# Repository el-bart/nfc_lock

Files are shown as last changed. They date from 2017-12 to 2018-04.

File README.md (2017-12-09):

# NFC lock

NFC-based, battery-powered lock for drawers, closets, etc.
android app used to control the module.

## done

* android app communicating with NFC both ways.

## TODO

* PCB with M24SR + STM8S003xx.
* SW for I2C communication with NFC tag.
* SW for controlling 2 servo mechanisms.
* 3D-printed box for servo and battery mounting.

## ideas / improvements

* configurable servos' min/max positions.
* android app look-and-feel update... ;)
* use ATECC508A crypto chip for limiting access to drawer/lock.

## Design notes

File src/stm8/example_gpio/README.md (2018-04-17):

# LED blinking example

example LED-blinking project, based on STM's example code.

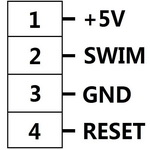
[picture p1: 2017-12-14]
doc/swim.jpg

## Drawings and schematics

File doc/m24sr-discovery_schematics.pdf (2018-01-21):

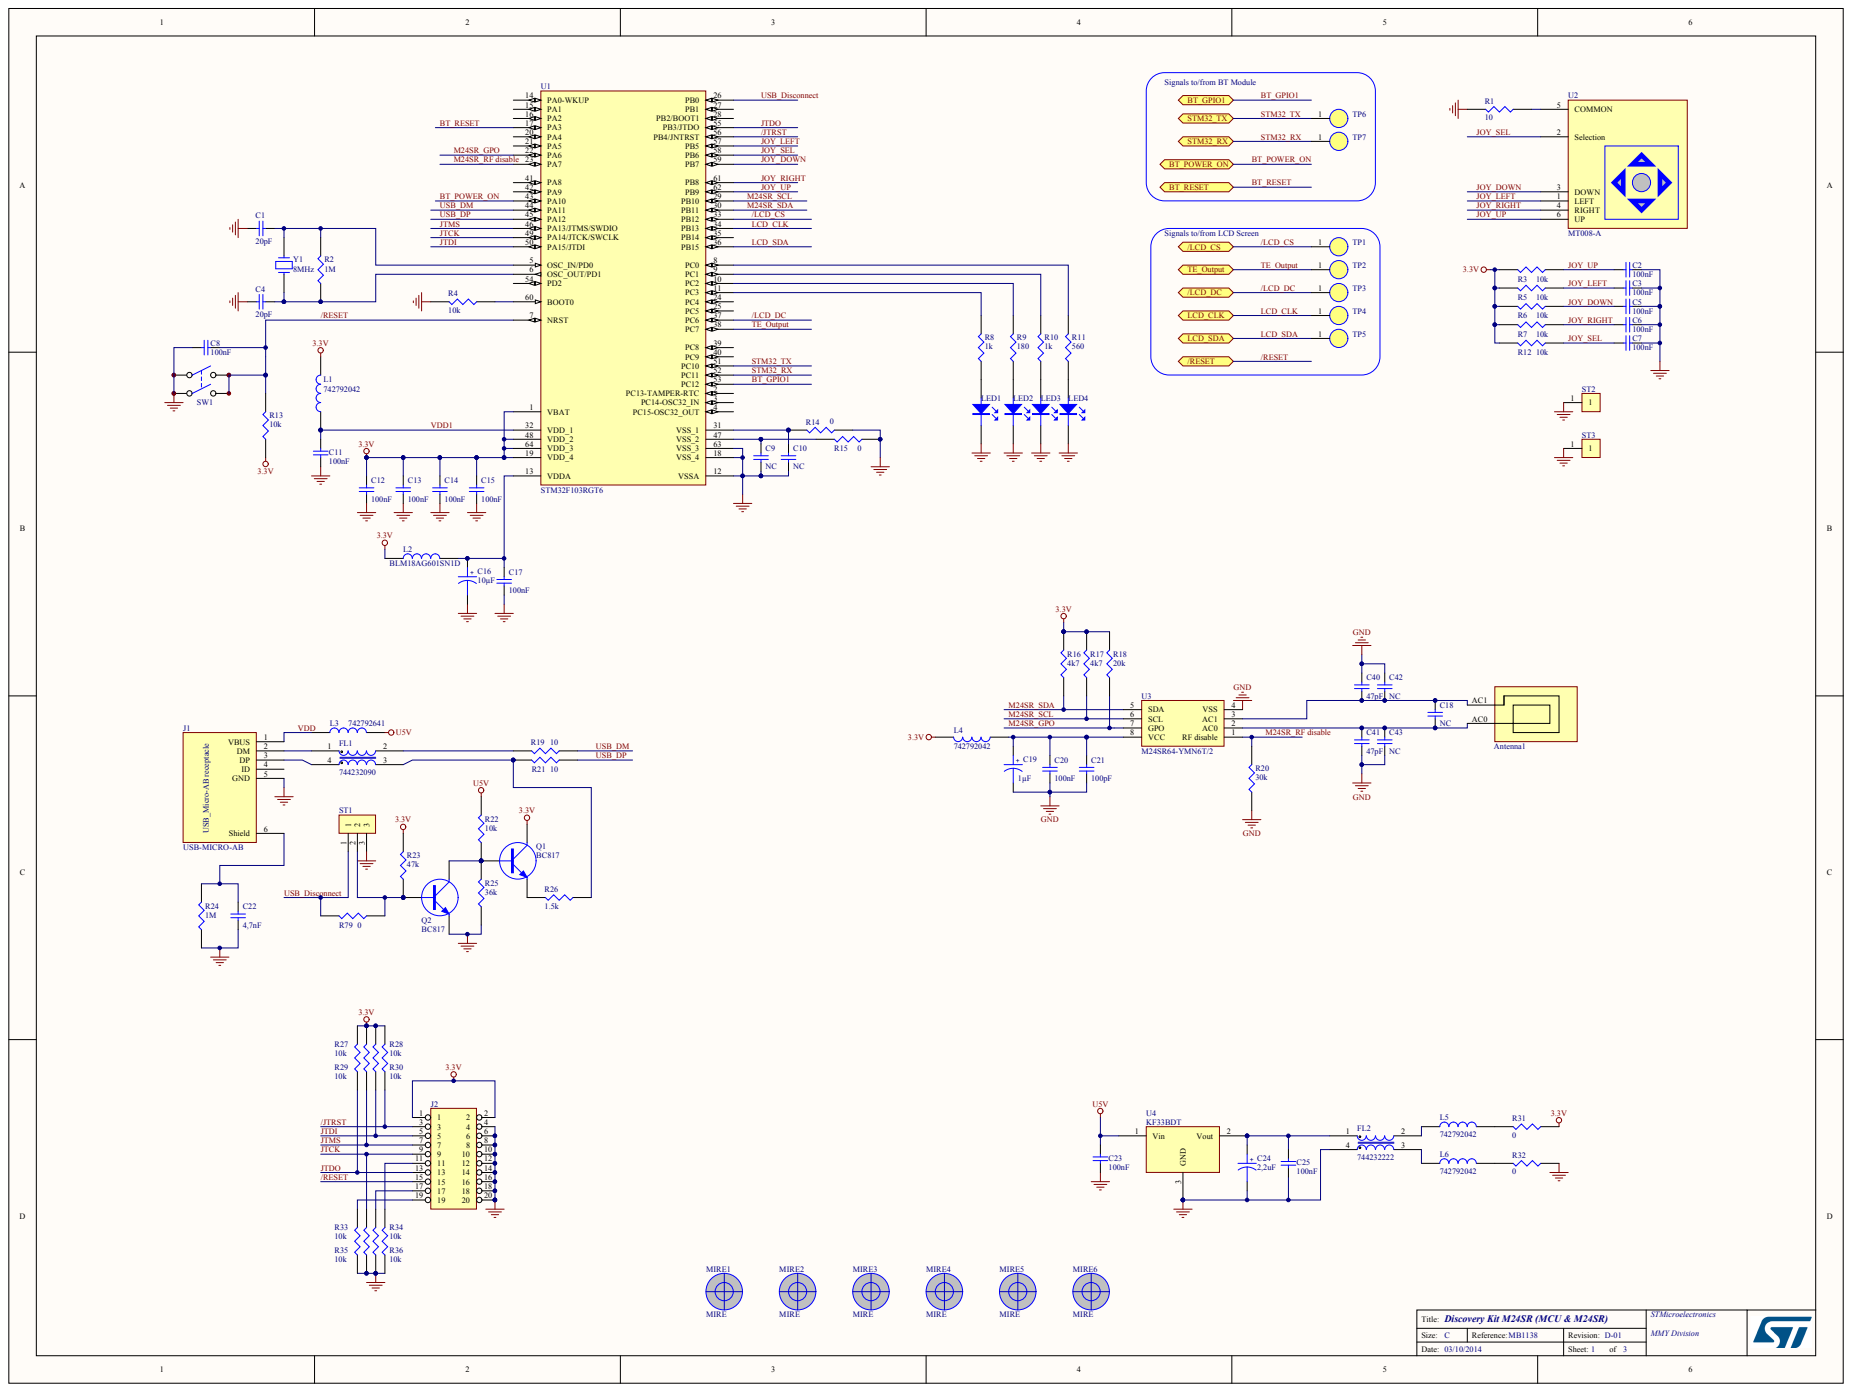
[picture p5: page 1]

Signals to/from BT Module

Signals to/from LCD Screen

Title: Discovery Kit M24SR (MCU & M24SR) | STMicroelectronics MMY Division

Size: C | Reference: MB1138 | Revision: D-01

Date: | | Sheet: of

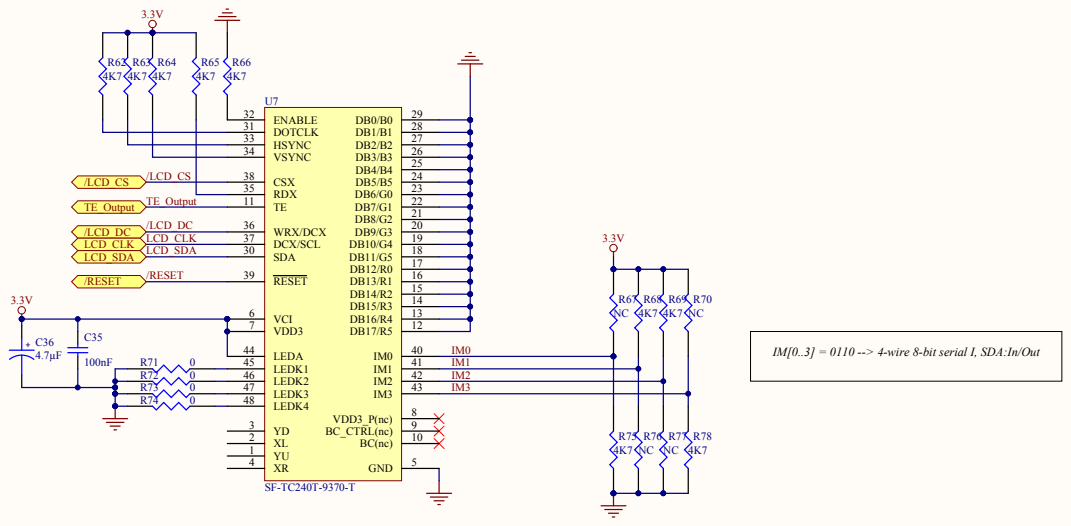
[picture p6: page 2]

IM[0..3] = 0110 --> 4-wire 8-bit serial I, SDA:In/Out

Discovery Kit M24SR (LCD Screen) | ST Microelectronics

A3 | | Revision:

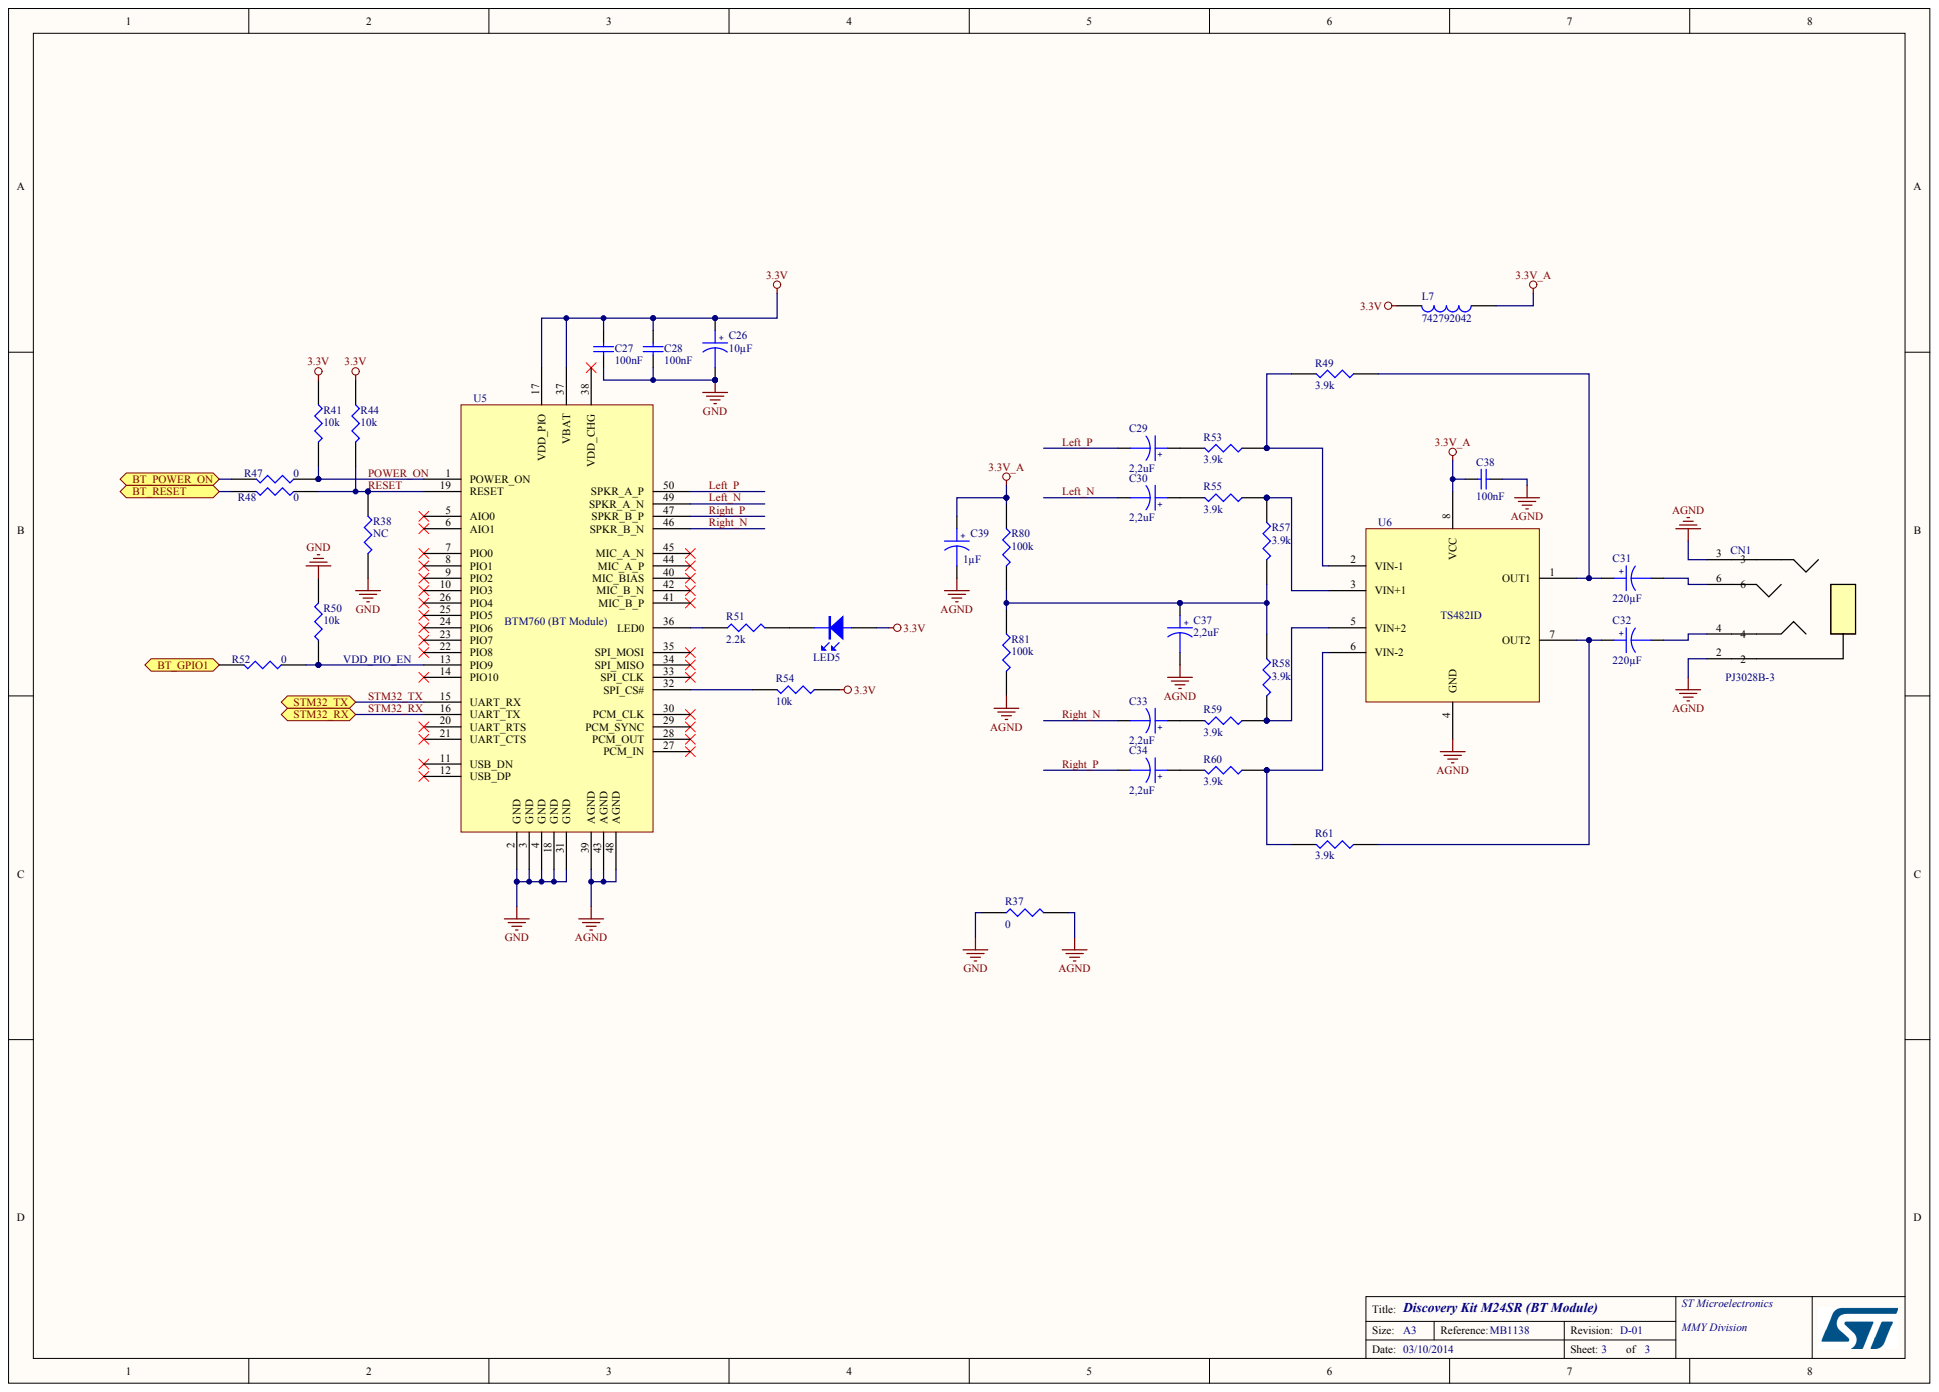
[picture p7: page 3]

Discovery Kit M24SR (BT Module) | ST Microelectronics

A3 | | Revision:

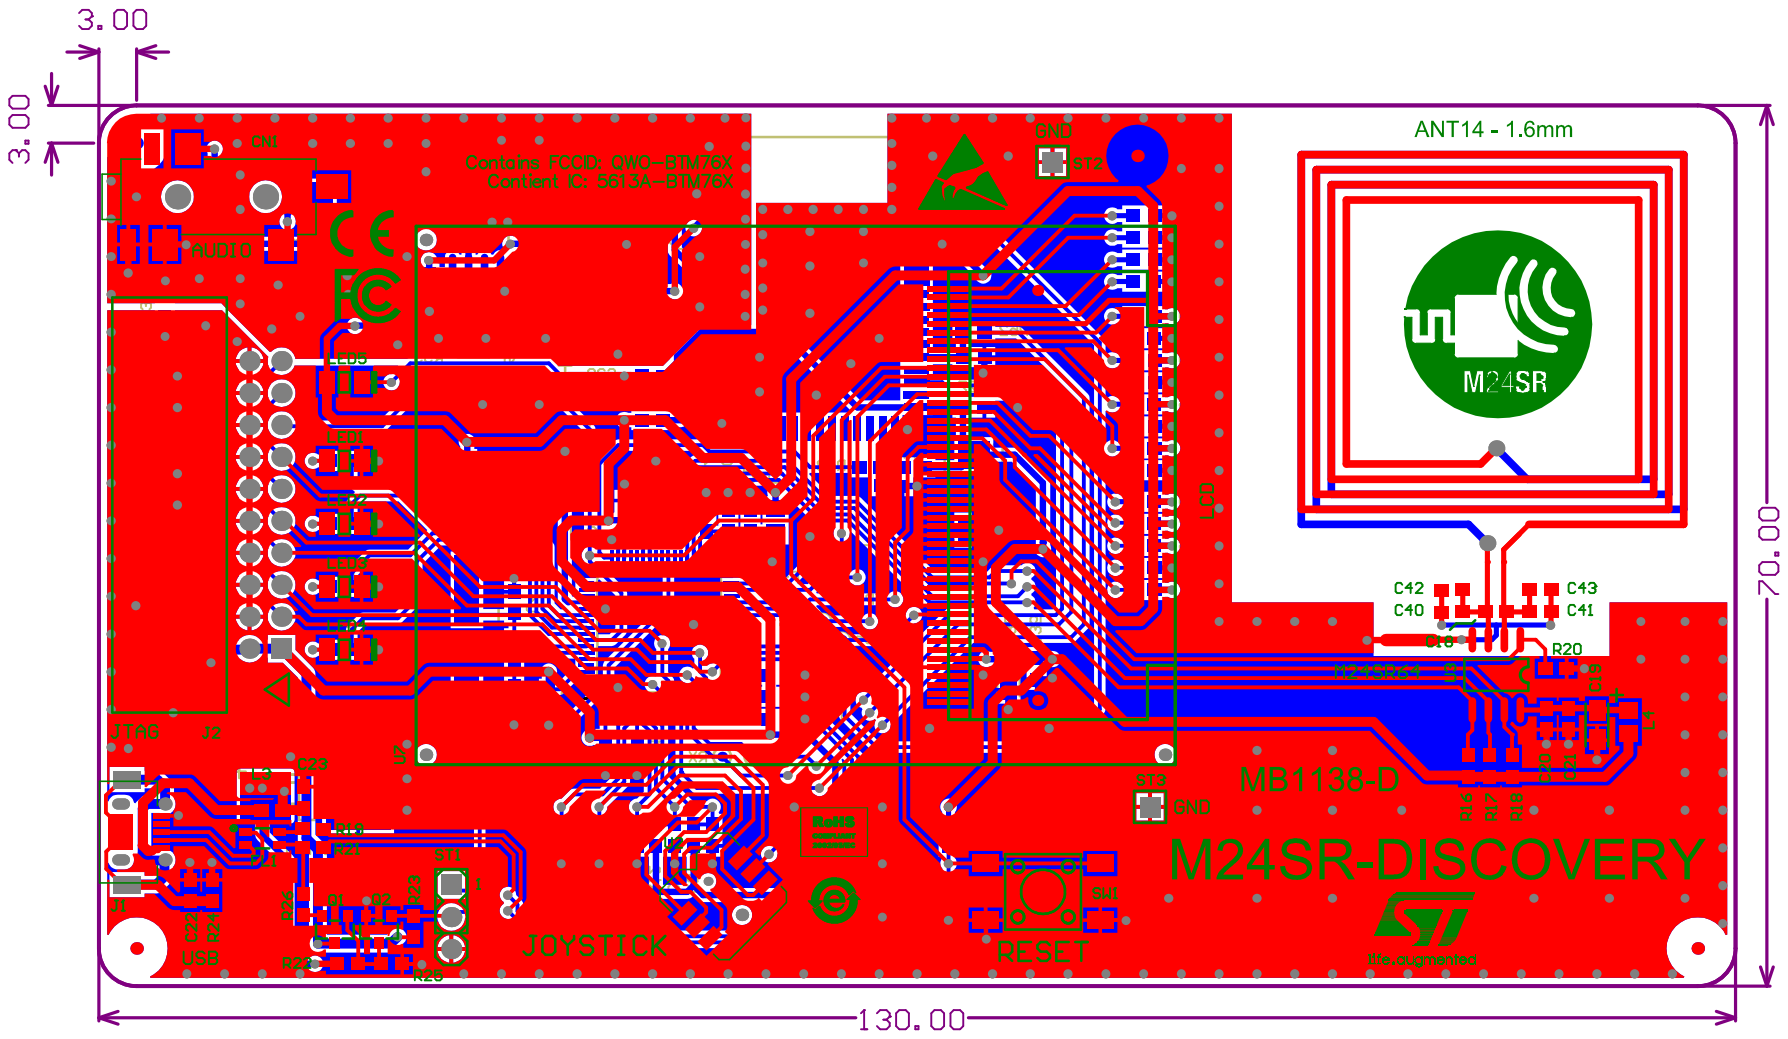
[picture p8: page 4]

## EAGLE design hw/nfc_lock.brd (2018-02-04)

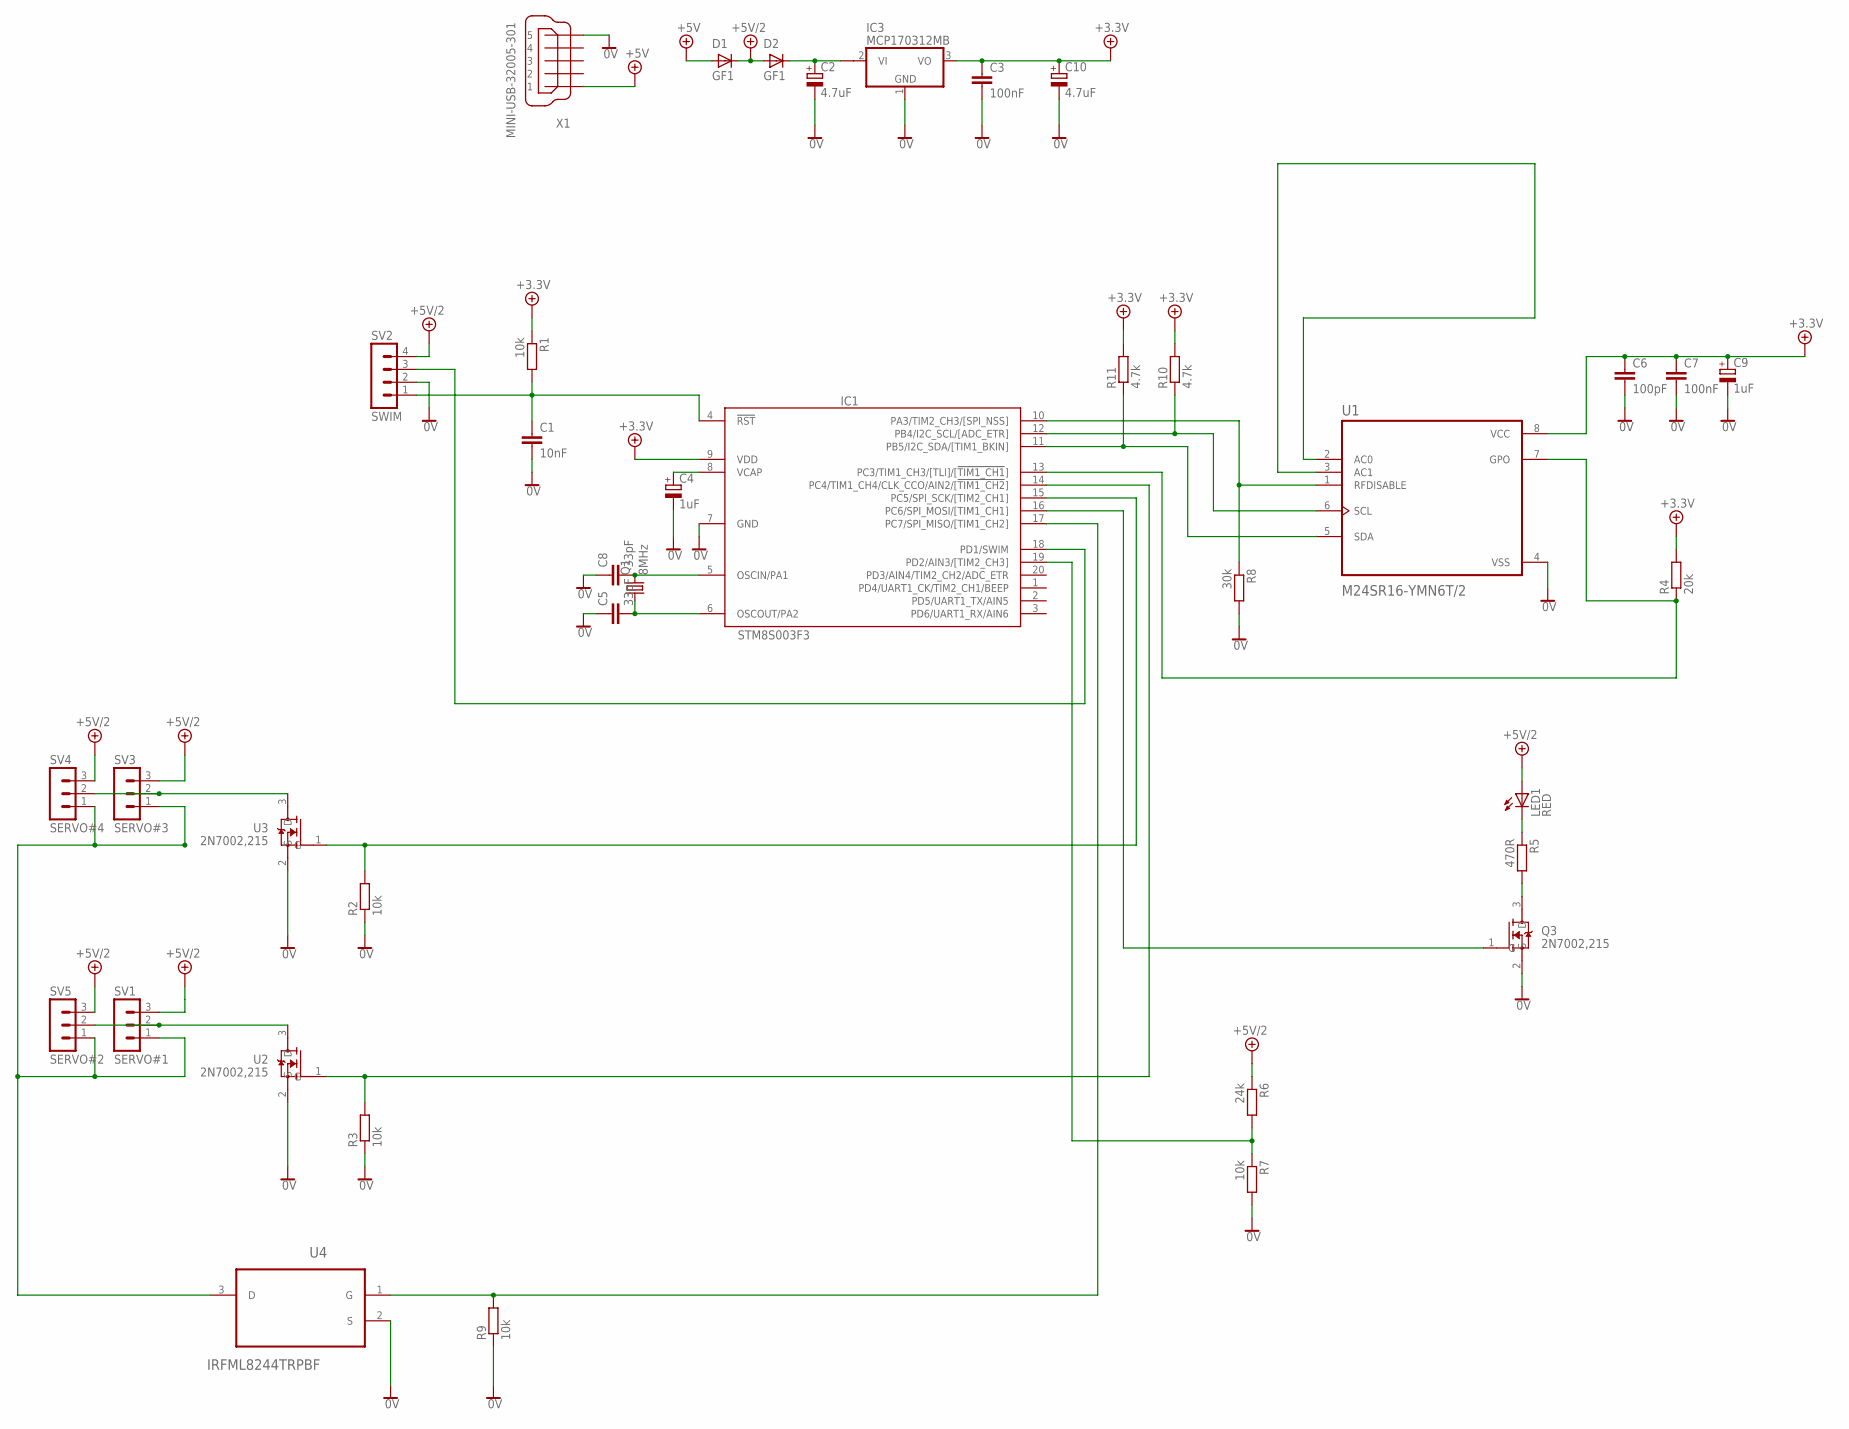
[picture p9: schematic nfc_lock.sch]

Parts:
C1: 10nF; C0603K
C2, C10: 4.7uF; 153CLV-0405
C3, C7: 100nF; C1206
C4, C9: 1uF; 153CLV-0405
C5, C8: 33pF; C0603K
C6: 100pF; C1206
D1, D2: GF1; SMA-DO214AC
IC1: STM8S003F3; TSSOP20
IC3: MCP170312MB; SOT89
LED1: RED; CHIP-LED0603
Q1: 8MHz; SM49
Q3: 2N7002,215; SOT95P230X110-3N
R1, R2, R3, R7, R9: 10k; R0805
R4: 20k; R0805
R5: 470R; R0805
R6: 24k; R0805
R8: 30k; R0805
R10, R11: 4.7k; R0805
SV1: SERVO#1; MA03-1
SV2: SWIM; MA04-1
SV3: SERVO#3; MA03-1
SV4: SERVO#4; MA03-1
SV5: SERVO#2; MA03-1
U1: M24SR16-YMN6T/2; SOIC127P600X175-8N
U2, U3: 2N7002,215; SOT95P230X110-3N
U4: IRFML8244TRPBF; SOT95P240X112-3N
X1: MINI-USB-32005-301; 32005-301

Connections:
0V: C1.2, C2.-, C3.2, C4.-, C5.1, C6.2, C7.2, C8.1, C9.-, C10.-, IC1.7 (GND), IC3.1 (GND), Q3.2 (S), R2.1, R3.1, R7.2, R8.2, R9.1, SV2.2, U1.4 (VSS), U2.2 (S), U3.2 (S), U4.2 (S), X1.5
+5V: D1.A, X1.1
+5V/1: C3.1, C6.1, C7.1, C9.+, C10.+, IC1.9 (VDD), IC3.3 (VO), R1.1, R4.2, R10.2, R11.2, U1.8 (VCC)
+5V/2: D1.K (C), D2.A, LED1.A, R6.1, SV1.3, SV2.4, SV3.3, SV4.3, SV5.3
ANTENA: U1.2 (AC0), U1.3 (AC1)
CTRL_LED: IC1.16 (PC6/SPI_MOSI/[TIM1_CH1]), Q3.1 (G)
unnamed: C2.+, D2.K (C), IC3.2@1 (VI1)
unnamed: C1.1, IC1.4 (!RST), R1.2, SV2.1
unnamed: IC1.18 (PD1/SWIM), SV2.3
unnamed: IC1.10 (PA3/TIM2_CH3/[SPI_NSS]), R8.1, U1.1 (RFDISABLE)
unnamed: IC1.13 (PC3/TIM1_CH3/[TLI]/[!TIM1_CH1!]), R4.1, U1.7 (GPO)
unnamed: SV1.2, SV5.2, U2.3 (D)
unnamed: SV3.2, SV4.2, U3.3 (D)
unnamed: LED1.C, R5.1
unnamed: Q3.3 (D), R5.2
unnamed: C4.+, IC1.8 (VCAP)
unnamed: C8.2, IC1.5 (OSCIN/PA1), Q1.2
unnamed: C5.2, IC1.6 (OSCOUT/PA2), Q1.1
unnamed: IC1.19 (PD2/AIN3/[TIM2_CH3]), R6.2, R7.1
SCL: IC1.12 (PB4/I2C_SCL/[ADC_ETR]), R10.1, U1.6 (SCL)
SDA: IC1.11 (PB5/I2C_SDA/[TIM1_BKIN]), R11.1, U1.5 (SDA)
SERVO_GND: SV1.1, SV3.1, SV4.1, SV5.1, U4.3 (D)
SERVO_PACK_1: IC1.14 (PC4/TIM1_CH4/CLK_CCO/AIN2/[!TIM1_CH2!]), R3.2, U2.1 (G)
SERVO_PACK_2: IC1.15 (PC5/SPI_SCK/[TIM2_CH1]), R2.2, U3.1 (G)
SERWO_PWR: IC1.17 (PC7/SPI_MISO/[TIM1_CH2]), R9.2, U4.1 (G)

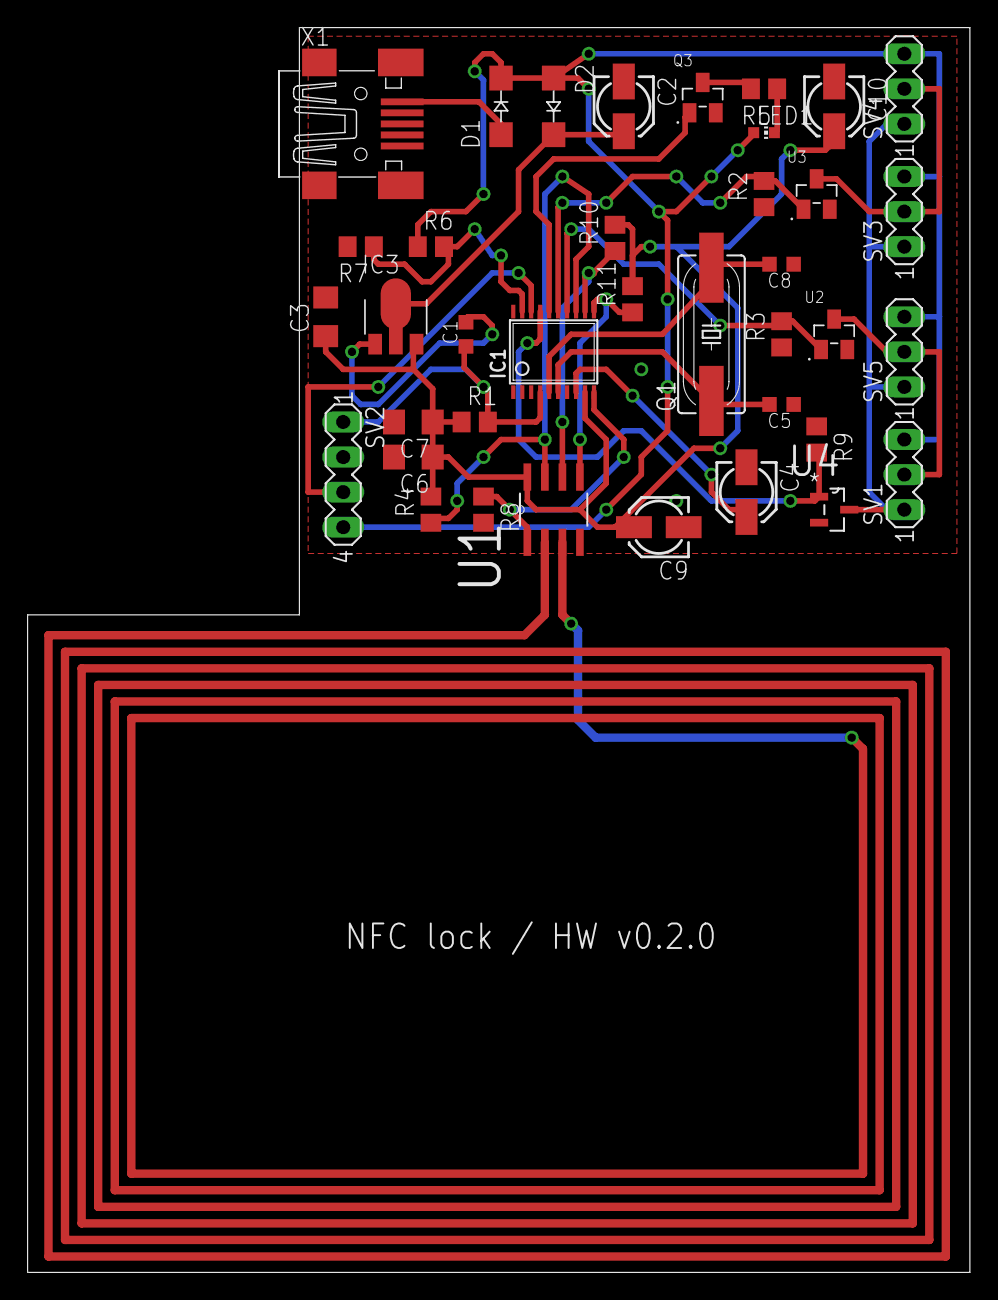
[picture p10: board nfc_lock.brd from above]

Board: 2 copper layers, 68.2 x 90.2 mm, 38 parts (0 on the bottom side), 25 nets.

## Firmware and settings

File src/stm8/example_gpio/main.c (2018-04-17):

#include "stm8s.h"

#ifdef STM8S003
#define LED_GPIO_PORT  (GPIOC)
#define LED_GPIO_PINS  (GPIO_PIN_6)
#else
#ifdef STM8S105
#define LED_GPIO_PORT  (GPIOD)
#define LED_GPIO_PINS  (GPIO_PIN_0)
#else
#error unknonw board/MCU...
#endif
#endif


void delay(uint16_t nCount)
{
  while (nCount != 0)
    nCount--;
}

void main(void)
{
  GPIO_Init(LED_GPIO_PORT, (GPIO_Pin_TypeDef)LED_GPIO_PINS, GPIO_MODE_OUT_PP_LOW_FAST);

  while (1)
  {
    GPIO_WriteReverse(LED_GPIO_PORT, (GPIO_Pin_TypeDef)LED_GPIO_PINS);
    delay(0xFFFF);
  }

}

#ifdef USE_FULL_ASSERT
void assert_failed(uint8_t* file, uint32_t line)
{
  (void)file;
  (void)line;
  while(1) { }
}
#endif

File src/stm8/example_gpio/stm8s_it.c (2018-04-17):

/**
  ******************************************************************************
  * @file     stm8s_it.c
  * @author   MCD Application Team
  * @version  V2.2.0
  * @date     30-September-2014
  * @brief    Main Interrupt Service Routines.
  ******************************************************************************
  * @attention
  *
  * <h2><center>&copy; COPYRIGHT 2014 STMicroelectronics</center></h2>
  *
  * Licensed under MCD-ST Liberty SW License Agreement V2, (the "License");
  * You may not use this file except in compliance with the License.
  * You may obtain a copy of the License at:
  *
  *        http://www.st.com/software_license_agreement_liberty_v2
  *
  * Unless required by applicable law or agreed to in writing, software 
  * distributed under the License is distributed on an "AS IS" BASIS, 
  * WITHOUT WARRANTIES OR CONDITIONS OF ANY KIND, either express or implied.
  * See the License for the specific language governing permissions and
  * limitations under the License.
  *
  ******************************************************************************
  */ 

/* Includes ------------------------------------------------------------------*/
#include "stm8s_it.h"

/* Private typedef -----------------------------------------------------------*/
/* Private define ------------------------------------------------------------*/
/* Private macro -------------------------------------------------------------*/
/* Private variables ---------------------------------------------------------*/
/* Private function prototypes -----------------------------------------------*/
/* Private functions ---------------------------------------------------------*/

/* Public functions ----------------------------------------------------------*/

/** @addtogroup GPIO_Toggle
  * @{
  */
#ifdef _COSMIC_
/**
  * @brief  Dummy interrupt routine
  * @param  None
  * @retval None
  */
INTERRUPT_HANDLER(NonHandledInterrupt, 25)
{
  /* In order to detect unexpected events during development,
     it is recommended to set a breakpoint on the following instruction.
  */
}
#endif /*_COSMIC_*/

/**
  * @brief  TRAP interrupt routine
  * @param  None
  * @retval None
  */
#if !defined(_SDCC_) || (SKIP_TRAPS!=1)    // SDCC patch: trap handling requires SDCC >=v3.4.3
INTERRUPT_HANDLER_TRAP(TRAP_IRQHandler)
{
  /* In order to detect unexpected events during development,
     it is recommended to set a breakpoint on the following instruction.
  */
}
#endif

/**
  * @brief  Top Level Interrupt routine
  * @param  None
  * @retval None
  */
INTERRUPT_HANDLER(TLI_IRQHandler, 0)
{
  /* In order to detect unexpected events during development,
     it is recommended to set a breakpoint on the following instruction.
  */
}

/**
  * @brief  Auto Wake Up Interrupt routine
  * @param  None
  * @retval None
  */
INTERRUPT_HANDLER(AWU_IRQHandler, 1)
{
  /* In order to detect unexpected events during development,
     it is recommended to set a breakpoint on the following instruction.
  */
}

/**
  * @brief  Clock Controller Interrupt routine
  * @param  None
  * @retval None
  */
INTERRUPT_HANDLER(CLK_IRQHandler, 2)
{
  /* In order to detect unexpected events during development,
     it is recommended to set a breakpoint on the following instruction.
  */
}

/**
  * @brief  External Interrupt PORTA Interrupt routine
  * @param  None
  * @retval None
  */
INTERRUPT_HANDLER(EXTI_PORTA_IRQHandler, 3)
{
  /* In order to detect unexpected events during development,
     it is recommended to set a breakpoint on the following instruction.
  */
}

/**
  * @brief  External Interrupt PORTB Interrupt routine
  * @param  None
  * @retval None
  */
INTERRUPT_HANDLER(EXTI_PORTB_IRQHandler, 4)
{
  /* In order to detect unexpected events during development,
     it is recommended to set a breakpoint on the following instruction.
  */
}

/**
  * @brief  External Interrupt PORTC Interrupt routine
  * @param  None
  * @retval None
  */
INTERRUPT_HANDLER(EXTI_PORTC_IRQHandler, 5)
{
  /* In order to detect unexpected events during development,
     it is recommended to set a breakpoint on the following instruction.
  */
}

/**
  * @brief  External Interrupt PORTD Interrupt routine
  * @param  None
  * @retval None
  */
INTERRUPT_HANDLER(EXTI_PORTD_IRQHandler, 6)
{
  /* In order to detect unexpected events during development,
     it is recommended to set a breakpoint on the following instruction.
  */
}

/**
  * @brief  External Interrupt PORTE Interrupt routine
  * @param  None
  * @retval None
  */
INTERRUPT_HANDLER(EXTI_PORTE_IRQHandler, 7)
{
  /* In order to detect unexpected events during development,
     it is recommended to set a breakpoint on the following instruction.
  */
}
#ifdef STM8S903
/**
  * @brief  External Interrupt PORTF Interrupt routine
  * @param  None
  * @retval None
  */
 INTERRUPT_HANDLER(EXTI_PORTF_IRQHandler, 8)
{
  /* In order to detect unexpected events during development,
     it is recommended to set a breakpoint on the following instruction.
  */
}
#endif /*STM8S903*/

#if defined (STM8S208) || defined (STM8AF52Ax)
/**
  * @brief CAN RX Interrupt routine.
  * @param  None
  * @retval None
  */
 INTERRUPT_HANDLER(CAN_RX_IRQHandler, 8)
{
  /* In order to detect unexpected events during development,
     it is recommended to set a breakpoint on the following instruction.
  */
}

/**
  * @brief  CAN TX Interrupt routine
  * @param  None
  * @retval None
  */
 INTERRUPT_HANDLER(CAN_TX_IRQHandler, 9)
{
  /* In order to detect unexpected events during development,
     it is recommended to set a breakpoint on the following instruction.
  */
}
#endif /*STM8S208 || STM8AF52Ax */

/**
  * @brief  SPI Interrupt routine
  * @param  None
  * @retval None
  */
INTERRUPT_HANDLER(SPI_IRQHandler, 10)
{
  /* In order to detect unexpected events during development,
     it is recommended to set a breakpoint on the following instruction.
  */
}

/**
  * @brief  Timer1 Update/Overflow/Trigger/Break Interrupt routine
  * @param  None
  * @retval None
  */
INTERRUPT_HANDLER(TIM1_UPD_OVF_TRG_BRK_IRQHandler, 11)
{
  /* In order to detect unexpected events during development,
     it is recommended to set a breakpoint on the following instruction.
  */
}

/**
  * @brief  Timer1 Capture/Compare Interrupt routine
  * @param  None
  * @retval None
  */
INTERRUPT_HANDLER(TIM1_CAP_COM_IRQHandler, 12)
{
  /* In order to detect unexpected events during development,
     it is recommended to set a breakpoint on the following instruction.
  */
}

#ifdef STM8S903
/**
  * @brief  Timer5 Update/Overflow/Break/Trigger Interrupt routine
  * @param  None
  * @retval None
  */
 INTERRUPT_HANDLER(TIM5_UPD_OVF_BRK_TRG_IRQHandler, 13)
{
  /* In order to detect unexpected events during development,
     it is recommended to set a breakpoint on the following instruction.
  */
}
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

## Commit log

2017-12-14 empty HW project
    [nfc_lock.brd, nfc_lock.sch]
2017-12-14 CPU + NFC
    [nfc_lock.brd, nfc_lock.sch]
2017-12-14 3.3 voltage regulators + I2C lines
    [nfc_lock.brd, nfc_lock.sch]
2017-12-14 3.3V/250mA voltage regulator
2017-12-14 power supply circut
    [nfc_lock.brd, nfc_lock.sch]
2017-12-14 TODO for non-soldering power supply
2017-12-14 power supply pads added
    [nfc_lock.brd, nfc_lock.sch]
2017-12-14 USB powersupply
    [nfc_lock.brd, nfc_lock.sch]
2017-12-14 added capacitors values
    [nfc_lock.brd, nfc_lock.sch]
2017-12-14 STM8/SWIM pin diagram
2017-12-14 power n-mosfet
2017-12-14 irfml8244pbf power n-mosfet eagle library
2017-12-14 added more lines and power n-mosfet to schema
    [nfc_lock.brd, nfc_lock.sch]
2017-12-14 TODO for LED
2017-12-14 2x n-mosfet for PWM of servos
    [nfc_lock.brd, nfc_lock.sch]
2017-12-14 mini-USB is now a power-supply :)
2017-12-19 added SWIM, connections to servos, signalling LED
    [nfc_lock.brd, nfc_lock.sch]
2017-12-19 resistors not LEDs for voltage split
    [nfc_lock.brd, nfc_lock.sch]
2018-01-07 antenna layout datasheet
2018-01-07 antenna drawed
    [nfc_lock.brd, nfc_lock.sch]
2018-01-07 added 2x more servos + some elements positioning
    [nfc_lock.brd, nfc_lock.sch]
2018-01-07 all airewires routed - input for some optimizations
    [nfc_lock.brd]
2018-01-07 PCB shrinked + board name and revision added
    [nfc_lock.brd]
2018-01-07 antenna's surronding space limited
    [nfc_lock.brd]
2018-01-07 fixed/approved all found warnings and errors
    [nfc_lock.brd, nfc_lock.sch]
2018-01-07 fixed packaging of 2n7002 transistor
    [nfc_lock.brd, nfc_lock.sch]
2018-01-07 all docs are now lower case
2018-01-07 added datasheet for transistor for LED driving
2018-01-07 USB moved to the very edge of the board
    [nfc_lock.brd]
2018-01-07 bard dimentions decreased even further
    [nfc_lock.brd]
2018-01-07 adjusted sizes of different components to match what i have in a closet... ;)
    [nfc_lock.brd, nfc_lock.sch]
2018-01-09 added on/off transistor for servos. replaced transistor for PWM servo control. added names to the most important signal lines.
    [nfc_lock.brd, nfc_lock.sch]
2018-01-20 schematic files for test antenas for M24SR
2018-01-21 schmatics and PCB layout for m24sr-discovery board
2018-01-22 more TODOs on issues with PCB
2018-01-22 reference gerber files for different antena designs from ST
2018-01-26 gerber files moved to a different dir
2018-01-26 top layer converted with a REA tool
    [matrix-m24sr_gerber_top.brd]
2018-01-26 bottom part of the antena layouts
    [matrix-m24sr_gerber_bottom.brd]
2018-01-31 added pull-ups for I2C and m24sr Vcc decoupling; changed antena type to single-sided
    [nfc_lock.brd, nfc_lock.sch]
2018-01-31 lcearence and spacing fixed
    [nfc_lock.brd]
2018-02-04 additional 4.7uF for general power decoupling
    [nfc_lock.brd, nfc_lock.sch]
2018-02-04 quartz's capacitors changed from 0402 to 0603K
    [nfc_lock.brd, nfc_lock.sch]
2018-03-26 interruption things
2018-03-26 added more source for evaluation board
2018-03-28 replaced example_beep that was designed for evaluation board (not discovery board), with example_gpio, that is slightly modified to work with discovery board
    [main.c, stm8s_it.c]
2018-03-28 1st PoC for blinking leds (found somewhere on the net)
2018-04-17 #ifdef for LED pins, on a per-board basis

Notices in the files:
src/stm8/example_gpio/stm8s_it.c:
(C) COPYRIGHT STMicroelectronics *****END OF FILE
